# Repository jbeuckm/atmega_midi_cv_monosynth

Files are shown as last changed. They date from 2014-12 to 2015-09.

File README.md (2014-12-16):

atmega_midi_cv
===============

Uses the Arduino MIDI library to operate two x MCP4822 12-bit DAC with internal voltage reference.

Largely based on http://www.experimentalistsanonymous.com/ve3wwg/doku.php?id=analog_synth_midi

Uses 4922 library from http://www.alhin.de/arduino

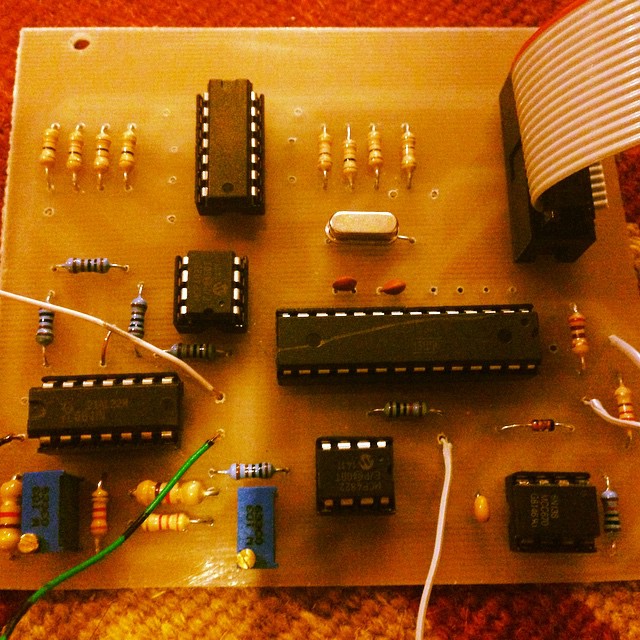
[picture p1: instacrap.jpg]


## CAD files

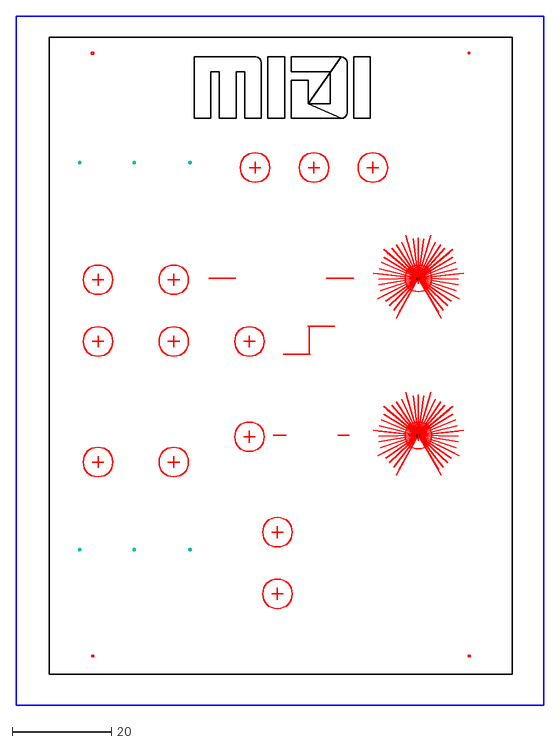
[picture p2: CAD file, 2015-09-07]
panel/monosynth_midi_cv_panel_print.dxf
106.3 x 138.7

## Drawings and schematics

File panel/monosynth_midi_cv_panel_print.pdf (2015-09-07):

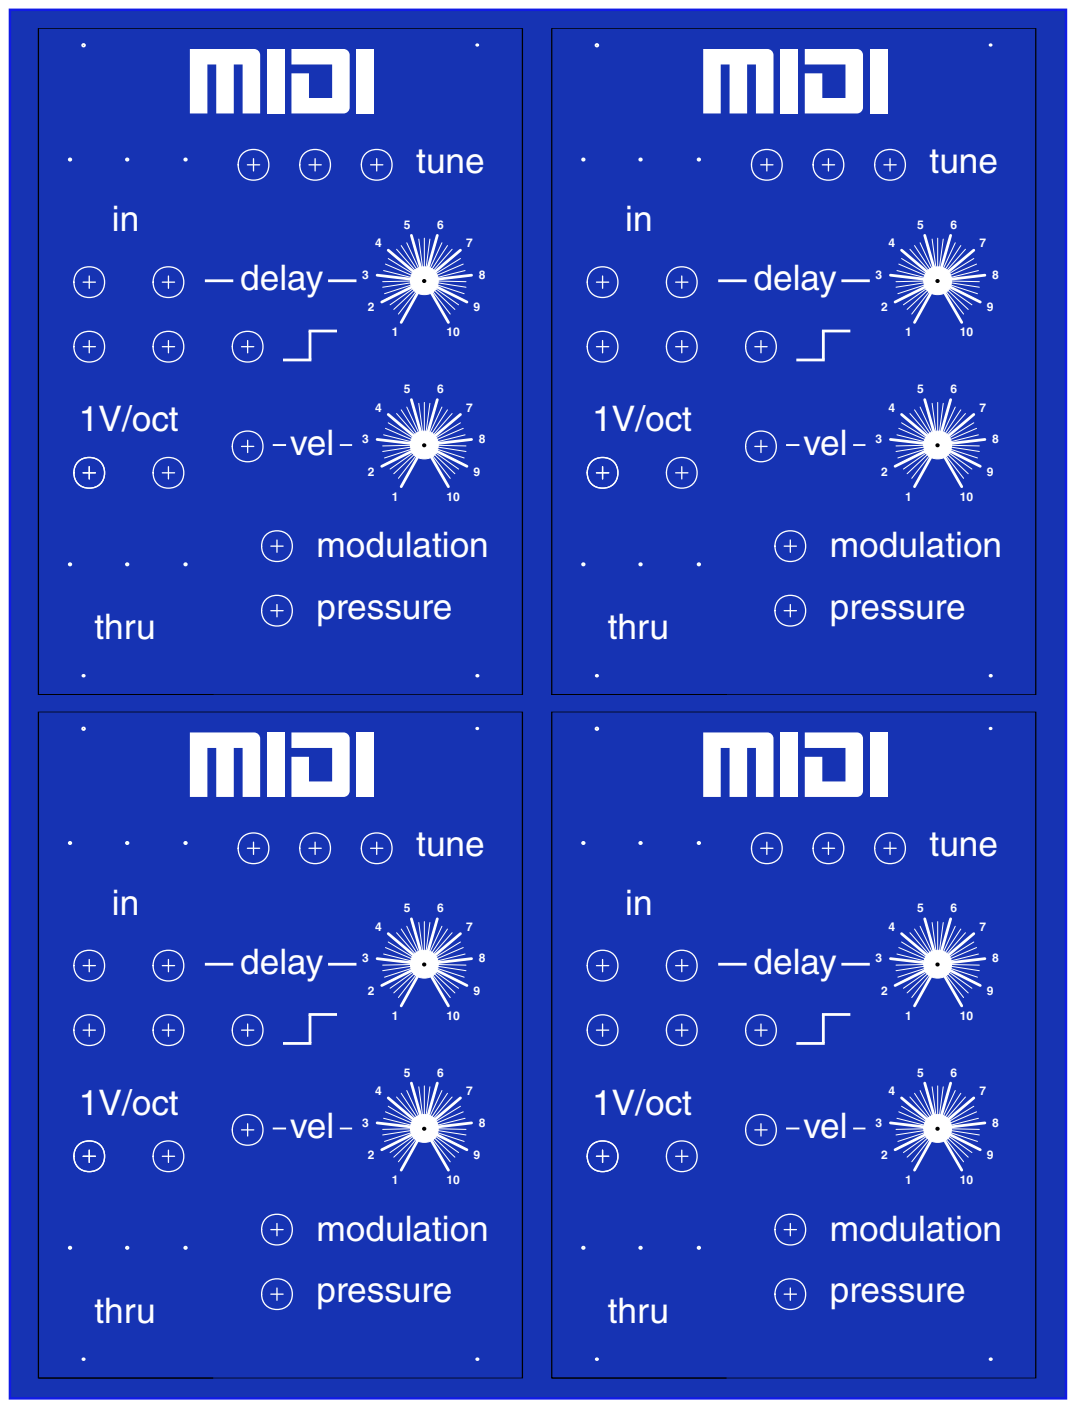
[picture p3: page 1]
vel; thru; delay; 1V/oct; modulation; pressure; tune

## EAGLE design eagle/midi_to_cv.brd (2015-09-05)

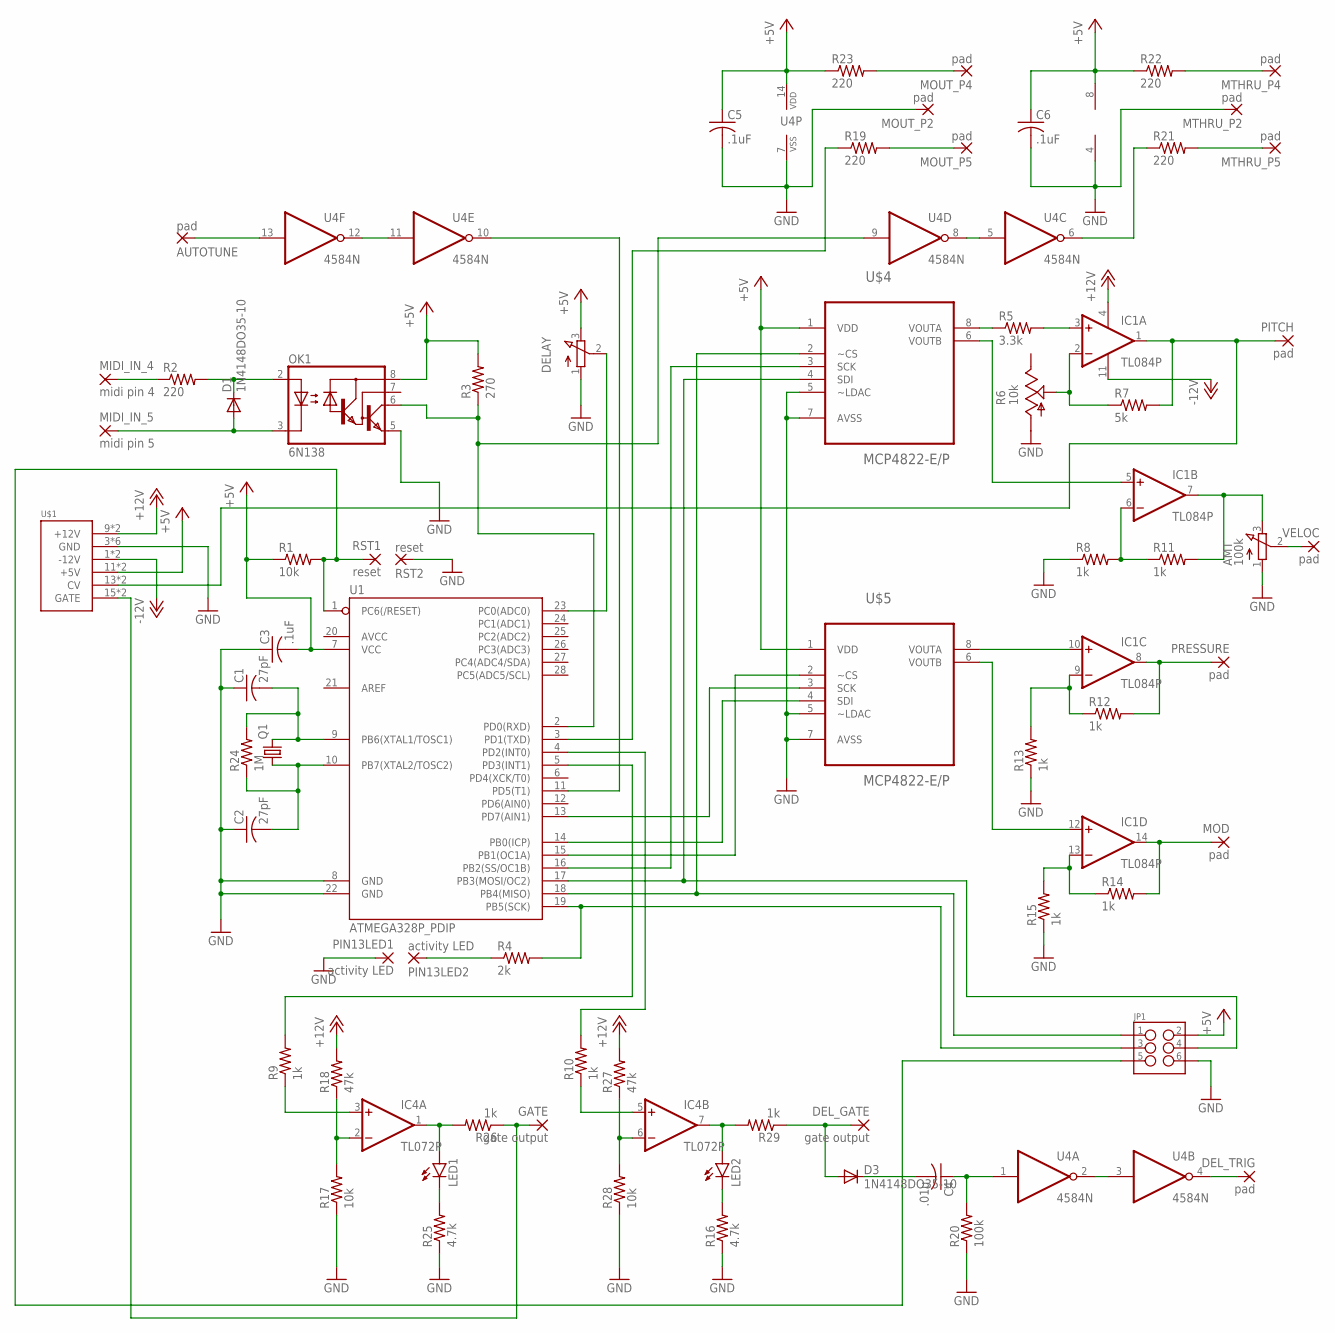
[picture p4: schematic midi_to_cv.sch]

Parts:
AMT: 100k; 3RP/1610N
AUTOTUNE: pad; 2,54/0,9
C1, C2: 27pF; C025-040X050
C3, C5, C6: .1uF; C050-024X044
C4: .01u; C050-024X044
D1, D3: 1N4148DO35-10; DO35-10
DELAY: 3RP/1610N
DEL_GATE: gate output; 2,54/0,9
DEL_TRIG: pad; 2,54/0,9
GATE: gate output; 2,54/0,9
IC1: TL084P; DIL14
IC4: TL072P; DIL08
JP1: M03X2NO_SILK; 2X3-NS
LED1, LED2: LED3MM
MIDI_IN_4: midi pin 4; 2,54/0,9
MIDI_IN_5: midi pin 5; 2,54/0,9
MOD: pad; 2,54/0,9
MOUT_P2, MOUT_P4, MOUT_P5: pad; 2,54/0,9
MTHRU_P2, MTHRU_P4, MTHRU_P5: pad; 2,54/0,9
OK1: 6N138; DIL08
PIN13LED1, PIN13LED2: activity LED; 2,54/0,9
PITCH: pad; 2,54/0,9
PRESSURE: pad; 2,54/0,9
Q1: CRYSTALHC33U-V; HC33U-V
R1, R17, R28: 10k; 0207/10
R2, R19, R21, R22, R23: 220; 0207/10
R3: 270; 0207/10
R4: 2k; 0207/10
R5: 3.3k; 0207/10
R6: 10k; B64W
R7: 5k; 0207/10
R8, R9, R10, R11, R12, R13, R14, R15, R26, R29: 1k; 0207/10
R16, R25: 4.7k; 0207/10
R18, R27: 47k; 0207/10
R20: 100k; 0207/10
R24: 1M; 0207/10
RST1, RST2: reset; 2,54/0,9
U1: ATMEGA328P_PDIP; DIL28-3
U4: 4584N; DIL14
U$1: POWER; POWER_16
U$4, U$5: MCP4822-E/P; DIP254P762X432-8
VELOC: pad; 2,54/0,9

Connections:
+5V: C3.2, C5.1, C6.1, DELAY.3 (E), IC4.8 (V+), JP1.2, OK1.8 (VCC), R1.1, R3.2, R22.1, R23.1, U1.7 (VCC), U4.14 (VDD), U$1.11 (+5V), U$1.12 (+5V), U$4.1 (VDD), U$5.1 (VDD)
+12V: IC1.4 (V+), R18.2, R27.2, U$1.9 (+12V), U$1.10 (+12V)
-12V: IC1.11 (V-), U$1.1 (-12V), U$1.2 (-12V)
GND: AMT.1 (A), C1.1, C2.1, C3.1, C5.2, C6.2, DELAY.1 (A), IC4.4 (V-), JP1.6, MOUT_P2.1, MTHRU_P2.1, OK1.5 (GND), PIN13LED1.1, R6.A, R8.1, R13.1, R15.1, R16.1, R17.1, R20.1, R25.1, R28.1, RST2.1, U1.8 (GND), U1.22 (GND), U4.7 (VSS), U$1.3 (GND), U$1.4 (GND), U$1.5 (GND), U$1.6 (GND), U$1.7 (GND), U$1.8 (GND), U$4.5 (~LDAC), U$4.7 (AVSS), U$5.5 (~LDAC), U$5.7 (AVSS)
unnamed: IC4.3 (+IN), R9.1
unnamed: R5.1, U$4.8 (VOUTA)
unnamed: D1.A, MIDI_IN_5.1, OK1.3 (C)
unnamed: C1.2, Q1.2, R24.2, U1.9 (PB6(XTAL1/TOSC1))
unnamed: C2.2, Q1.1, R24.1, U1.10 (PB7(XTAL2/TOSC2))
unnamed: IC1.3 (+IN), R5.2
unnamed: D1.C, OK1.2 (A), R2.2
unnamed: MIDI_IN_4.1, R2.1
unnamed: IC1.1 (OUT), PITCH.1, R7.2, U$1.13 (CV), U$1.14 (CV)
unnamed: JP1.3, R4.2, U1.19 (PB5(SCK))
unnamed: PIN13LED2.1, R4.1
unnamed: IC1.2 (-IN), R6.S, R7.1
unnamed: IC1.6 (-IN), R8.2, R11.1
unnamed: IC1.5 (+IN), U$4.6 (VOUTB)
unnamed: IC4.2 (-IN), R17.2, R18.1
unnamed: IC4.1 (OUT), LED1.A, R26.2
unnamed: AMT.3 (E), IC1.7 (OUT), R11.2
unnamed: IC1.10 (+IN), U$5.8 (VOUTA)
unnamed: IC1.8 (OUT), PRESSURE.1, R12.2
unnamed: IC1.9 (-IN), R12.1, R13.2
unnamed: IC1.14 (OUT), MOD.1, R14.2
unnamed: IC1.13 (-IN), R14.1, R15.2
unnamed: U1.14 (PB0(ICP)), U$5.4 (SDI)
unnamed: IC1.12 (+IN), U$5.6 (VOUTB)
unnamed: U1.16 (PB2(SS/OC1B)), U$4.3 (SCK)
unnamed: JP1.4, U1.17 (PB3(MOSI/OC2)), U$4.4 (SDI)
unnamed: DELAY.2 (S), U1.23 (PC0(ADC0))
unnamed: U1.13 (PD7(AIN1)), U$5.3 (SCK)
unnamed: U1.15 (PB1(OC1A)), U$5.2 (~CS)
unnamed: OK1.6 (VO), R3.1, U1.2 (PD0(RXD)), U4.9 (I)
unnamed: GATE.1, R26.1, U$1.15 (GATE), U$1.16 (GATE)
unnamed: R10.2, U1.4 (PD2(INT0))
unnamed: R9.2, U1.5 (PD3(INT1))
unnamed: AUTOTUNE.1, U4.13 (I)
unnamed: D3.A, DEL_GATE.1, R29.1
unnamed: LED2.K (C), R16.2
unnamed: U4.11 (I), U4.12 (O)
unnamed: U1.11 (PD5(T1)), U4.10 (O)
unnamed: U4.5 (I), U4.8 (O)
unnamed: U4.2 (O), U4.3 (I)
unnamed: C4.1, R20.2, U4.1 (I)
unnamed: IC4.5 (+IN), R10.1
unnamed: JP1.5, R1.2, RST1.1, U1.1 (PC6(/RESET))
unnamed: IC4.6 (-IN), R27.1, R28.2
unnamed: JP1.1, U1.18 (PB4(MISO)), U$4.2 (~CS)
unnamed: MOUT_P5.1, R19.2
unnamed: LED1.K (C), R25.2
unnamed: C4.2, D3.C
unnamed: DEL_TRIG.1, U4.4 (O)
unnamed: R21.1, U4.6 (O)
unnamed: AMT.2 (S), VELOC.1
unnamed: MTHRU_P5.1, R21.2
unnamed: IC4.7 (OUT), LED2.A, R29.2
unnamed: MTHRU_P4.1, R22.2
unnamed: MOUT_P4.1, R23.2
unnamed: R19.1, U1.3 (PD1(TXD))

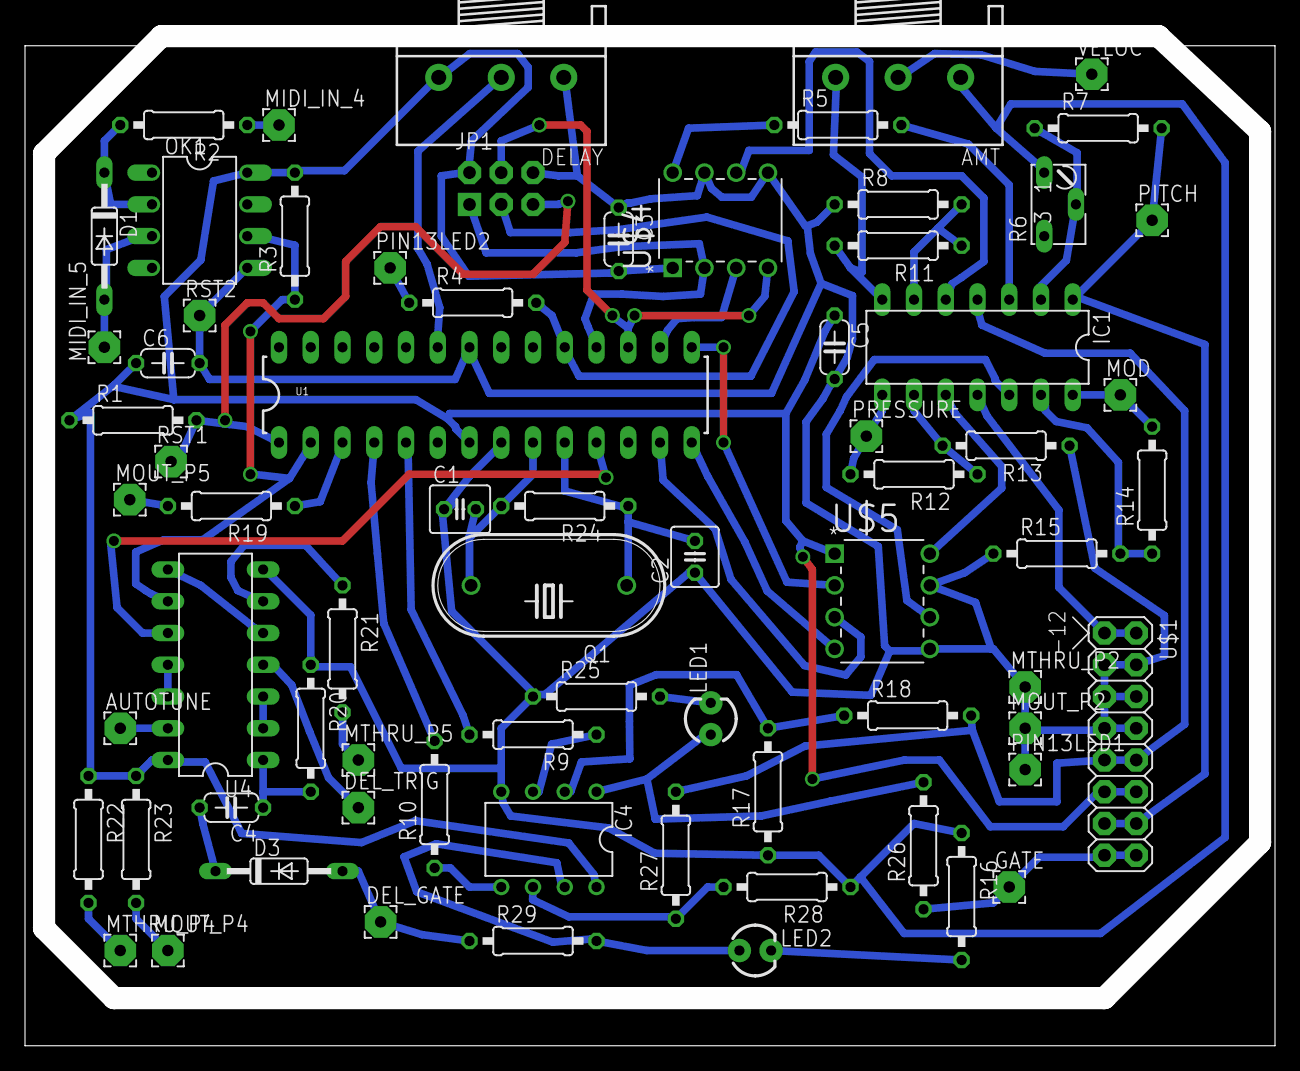
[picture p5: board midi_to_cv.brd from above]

Board: 2 copper layers, 100.0 x 80.8 mm, 71 parts (0 on the bottom side), 60 nets.

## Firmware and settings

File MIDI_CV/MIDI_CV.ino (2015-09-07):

#include <MIDI.h>
#include "AH_MCP4922.h"

#define LED 13   		    // LED pin on Arduino Uno

#define GATE_PIN 3
#define DELAYED_GATE_PIN 2

#define DELAY_PERIOD_PIN A0

//define AnalogOutput (MOSI_pin, SCK_pin, CS_pin, DAC_x, GAIN) 

AH_MCP4922 AnalogOutput1(11,10,12,LOW,LOW);
AH_MCP4922 AnalogOutput2(11,10,12,HIGH,LOW);

AH_MCP4922 AnalogOutput3(8,7,9,LOW,LOW);
AH_MCP4922 AnalogOutput4(8,7,9,HIGH,LOW);

int liveNoteCount = 0;
int pitchbendOffset = 0;
int baseNoteFrequency;

int delayCounter;
boolean prepareDelayGateOn = false;
boolean prepareDelayGateOff = false;
int delayLength;

MIDI_CREATE_DEFAULT_INSTANCE();

byte selectedChannel = 17;

void handleNoteOn(byte channel, byte pitch, byte velocity)
{
  if (selectedChannel == 17) {
    selectedChannel = channel;
  }
  else if (channel != selectedChannel) {
    return;
  }
  
  liveNoteCount++;
  
  baseNoteFrequency = (pitch - 12) * 42;
  AnalogOutput1.setValue(baseNoteFrequency + pitchbendOffset);
  AnalogOutput2.setValue(velocity * 32);

  digitalWrite(GATE_PIN, HIGH);
  
  prepareDelayGateOff = false;
  delayLength = analogRead(DELAY_PERIOD_PIN);
  delayCounter = 0;
  prepareDelayGateOn = true;
}

void handleNoteOff(byte channel, byte pitch, byte velocity)
{
  if (channel != selectedChannel) {
    return;
  }
  liveNoteCount--;
  
  if (liveNoteCount == 0) {
    digitalWrite(GATE_PIN, LOW);
  
    prepareDelayGateOn = false;
    delayLength = analogRead(DELAY_PERIOD_PIN);
    delayCounter = 0;
    prepareDelayGateOff = true;
  }
}


ISR(TIMER1_COMPA_vect) {
  if (prepareDelayGateOn) {
    delayCounter++;
    if (delayCounter >= delayLength) {
      digitalWrite(DELAYED_GATE_PIN, HIGH);
      prepareDelayGateOn = false;
    }
  }
  else if (prepareDelayGateOff) {
    delayCounter++;
    if (delayCounter >= delayLength) {
      digitalWrite(DELAYED_GATE_PIN, LOW);
      prepareDelayGateOff = false;
    }
  }    
}


void handleControlChange(byte channel, byte number, byte value)
{
  if (channel != selectedChannel) {
    return;
  }
  if (number == 1) {
    AnalogOutput4.setValue(value * 32);
  }
}

void handleChannelPressure(byte channel, byte value)
{
  if (channel != selectedChannel) {
    return;
  }

  AnalogOutput3.setValue(value * 32);
}


void handlePitchBend(byte channel, int bend)
{
  pitchbendOffset = bend >> 4;

  AnalogOutput1.setValue(baseNoteFrequency + pitchbendOffset);
}


// -----------------------------------------------------------------------------

void setup()
{
    pinMode(LED, OUTPUT);

    pinMode(GATE_PIN, OUTPUT);
    pinMode(DELAYED_GATE_PIN, OUTPUT);
    
    MIDI.setHandleNoteOn(handleNoteOn);
    MIDI.setHandleNoteOff(handleNoteOff);
    MIDI.setHandlePitchBend(handlePitchBend);
    
    MIDI.setHandleControlChange(handleControlChange);
    MIDI.setHandleAfterTouchChannel(handleChannelPressure);


    cli();//stop interrupts
    
    //set timer1 interrupt at 1kHz
    TCCR1A = 0;// set entire TCCR1A register to 0
    TCCR1B = 0;// same for TCCR1B
    TCNT1  = 0;//initialize counter value to 0;
    // set timer count for 1khz increments
    OCR1A = 1999;// = (16*10^6) / (1000*8) - 1
    // turn on CTC mode
    TCCR1B |= (1 << WGM12);
    // Set CS11 bit for 8 prescaler
    TCCR1B |= (1 << CS11);   
    // enable timer compare interrupt
    TIMSK1 |= (1 << OCIE1A);
    
    sei();//allow interrupts


    MIDI.begin(10);
    
    // C8 at full velocity for calibration on powerup
    handleNoteOn(17, 108, 127);

    liveNoteCount--;
}

void loop()
{
    MIDI.read();
}

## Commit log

2014-10-25 restructured by arduino
2014-11-09 set pitch and velocity cv before trigger
2014-11-16 adding cambam and eagle files
    [midi_to_cv.brd, midi_to_cv.sch]
2014-11-17 adding four programmable gates outputs
    [midi_to_cv.brd]
2014-11-18 trying to autoroute
    [midi_to_cv.brd]
2014-11-21 power to the op amps
    [midi_to_cv.brd, midi_to_cv.sch]
2014-11-21 toward a routing for the gates
    [midi_to_cv.brd]
2014-12-06 routed with jumpers for gates and one via
    [midi_to_cv.brd, midi_to_cv.sch]
2014-12-15 conforming to the schematic
    [midi_to_cv.brd]
2014-12-16 corrected to smaller xtal package
    [midi_to_cv.brd, midi_to_cv.sch]
2014-12-17 will add iscp header
    [midi_to_cv.brd, midi_to_cv.sch]
2015-06-18 this interface is getting sirius
    [midi_to_cv.brd, midi_to_cv.sch]
2015-09-03 updated gate circuits and normalled gate and cv to power connector and swapped vel and mod outputs
    [midi_to_cv.brd, midi_to_cv.sch]
2015-09-03 parts basically on board and 072 powered
    [midi_to_cv.brd, midi_to_cv.sch]
2015-09-04 swapped some gates and rearranged to layout
    [midi_to_cv.brd, midi_to_cv.sch]
2015-09-04 arranged power to the right and getting close to routed
    [midi_to_cv.brd]
2015-09-05 ready to cut layout
    [midi_to_cv.brd, midi_to_cv.sch]
2015-09-06 prototype coming alive with this software update
2015-09-07 cam of panel
    [monosynth_midi_cv_panel_print.dxf]

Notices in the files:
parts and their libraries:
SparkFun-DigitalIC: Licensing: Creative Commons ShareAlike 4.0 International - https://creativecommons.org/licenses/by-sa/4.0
